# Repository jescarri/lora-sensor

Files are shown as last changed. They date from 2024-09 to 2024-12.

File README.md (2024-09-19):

# lora-sensor

## Getting started

To make it easy for you to get started with GitLab, here's a list of recommended next steps.

Already a pro? Just edit this README.md and make it your own. Want to make it easy? [Use the template at the bottom](#editing-this-readme)!

## Add your files

- [ ] [Create](https://docs.gitlab.com/ee/user/project/repository/web_editor.html#create-a-file) or [upload](https://docs.gitlab.com/ee/user/project/repository/web_editor.html#upload-a-file) files
- [ ] [Add files using the command line](https://docs.gitlab.com/ee/gitlab-basics/add-file.html#add-a-file-using-the-command-line) or push an existing Git repository with the following command:

```
cd existing_repo
git remote add origin https://gitlab.identitylabs.mx/iot/lora-sensor.git
git branch -M master
git push -uf origin master
```

## Integrate with your tools

- [ ] [Set up project integrations](https://gitlab.identitylabs.mx/iot/lora-sensor/-/settings/integrations)

## Collaborate with your team

- [ ] [Invite team members and collaborators](https://docs.gitlab.com/ee/user/project/members/)
- [ ] [Create a new merge request](https://docs.gitlab.com/ee/user/project/merge_requests/creating_merge_requests.html)
- [ ] [Automatically close issues from merge requests](https://docs.gitlab.com/ee/user/project/issues/managing_issues.html#closing-issues-automatically)
- [ ] [Enable merge request approvals](https://docs.gitlab.com/ee/user/project/merge_requests/approvals/)
- [ ] [Set auto-merge](https://docs.gitlab.com/ee/user/project/merge_requests/merge_when_pipeline_succeeds.html)

## Test and Deploy

Use the built-in continuous integration in GitLab.

- [ ] [Get started with GitLab CI/CD](https://docs.gitlab.com/ee/ci/quick_start/index.html)
- [ ] [Analyze your code for known vulnerabilities with Static Application Security Testing (SAST)](https://docs.gitlab.com/ee/user/application_security/sast/)
- [ ] [Deploy to Kubernetes, Amazon EC2, or Amazon ECS using Auto Deploy](https://docs.gitlab.com/ee/topics/autodevops/requirements.html)
- [ ] [Use pull-based deployments for improved Kubernetes management](https://docs.gitlab.com/ee/user/clusters/agent/)
- [ ] [Set up protected environments](https://docs.gitlab.com/ee/ci/environments/protected_environments.html)

***

# Editing this README

When you're ready to make this README your own, just edit this file and use the handy template below (or feel free to structure it however you want - this is just a starting point!). Thanks to [makeareadme.com](https://www.makeareadme.com/) for this template.

## Suggestions for a good README

Every project is different, so consider which of these sections apply to yours. The sections used in the template are suggestions for most open source projects. Also keep in mind that while a README can be too long and detailed, too long is better than too short. If you think your README is too long, consider utilizing another form of documentation rather than cutting out information.

## Name
Choose a self-explaining name for your project.

## Description
Let people know what your project can do specifically. Provide context and add a link to any reference visitors might be unfamiliar with. A list of Features or a Background subsection can also be added here. If there are alternatives to your project, this is a good place to list differentiating factors.

## Badges
On some READMEs, you may see small images that convey metadata, such as whether or not all the tests are passing for the project. You can use Shields to add some to your README. Many services also have instructions for adding a badge.

## Visuals
Depending on what you are making, it can be a good idea to include screenshots or even a video (you'll frequently see GIFs rather than actual videos). Tools like ttygif can help, but check out Asciinema for a more sophisticated method.

## Installation
Within a particular ecosystem, there may be a common way of installing things, such as using Yarn, NuGet, or Homebrew. However, consider the possibility that whoever is reading your README is a novice and would like more guidance. Listing specific steps helps remove ambiguity and gets people to using your project as quickly as possible. If it only runs in a specific context like a particular programming language version or operating system or has dependencies that have to be installed manually, also add a Requirements subsection.

## Usage
Use examples liberally, and show the expected output if you can. It's helpful to have inline the smallest example of usage that you can demonstrate, while providing links to more sophisticated examples if they are too long to reasonably include in the README.

## Support
Tell people where they can go to for help. It can be any combination of an issue tracker, a chat room, an email address, etc.

## Roadmap
If you have ideas for releases in the future, it is a good idea to list them in the README.

## Contributing
State if you are open to contributions and what your requirements are for accepting them.

For people who want to make changes to your project, it's helpful to have some documentation on how to get started. Perhaps there is a script that they should run or some environment variables that they need to set. Make these steps explicit. These instructions could also be useful to your future self.

You can also document commands to lint the code or run tests. These steps help to ensure high code quality and reduce the likelihood that the changes inadvertently break something. Having instructions for running tests is especially helpful if it requires external setup, such as starting a Selenium server for testing in a browser.

## Authors and acknowledgment
Show your appreciation to those who have contributed to the project.

## License
For open source projects, say how it is licensed.

## Project status
If you have run out of energy or time for your project, put a note at the top of the README saying that development has slowed down or stopped completely. Someone may choose to fork your project or volunteer to step in as a maintainer or owner, allowing your project to keep going. You can also make an explicit request for maintainers.

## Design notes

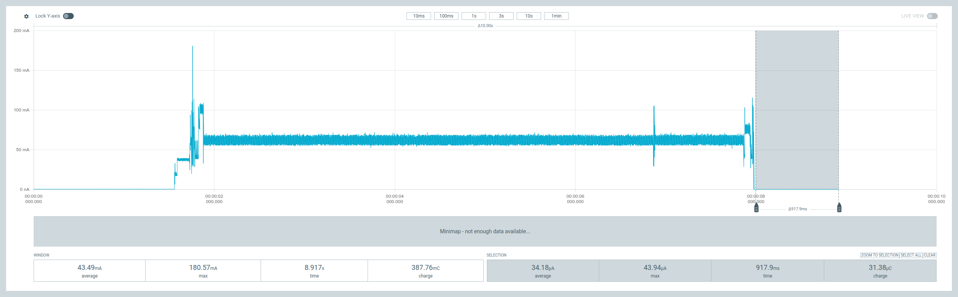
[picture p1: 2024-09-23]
power-profile/radio_vdd_enable_sleep_zoom1.png

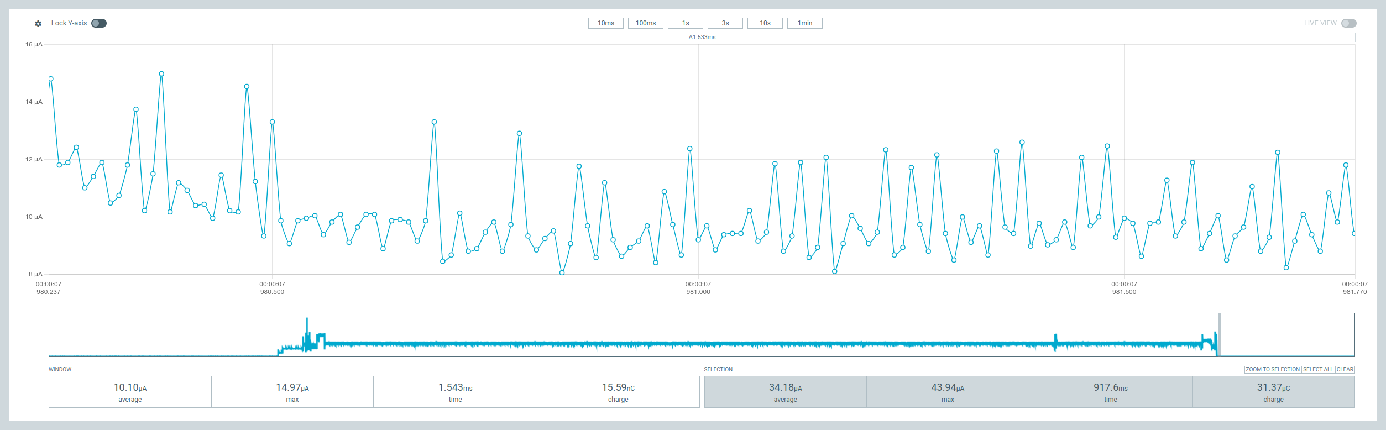
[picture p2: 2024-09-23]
power-profile/radio_vdd_enable_sleep_zoom2.png

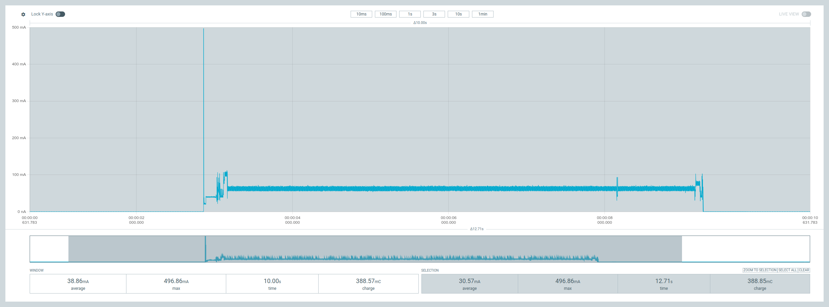
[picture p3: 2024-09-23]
power-profile/no_radio_vdd.png

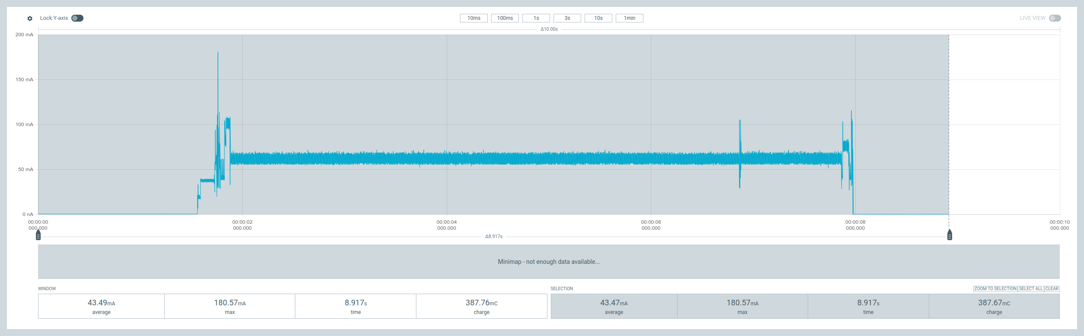
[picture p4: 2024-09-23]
power-profile/radio_vdd_enable.png

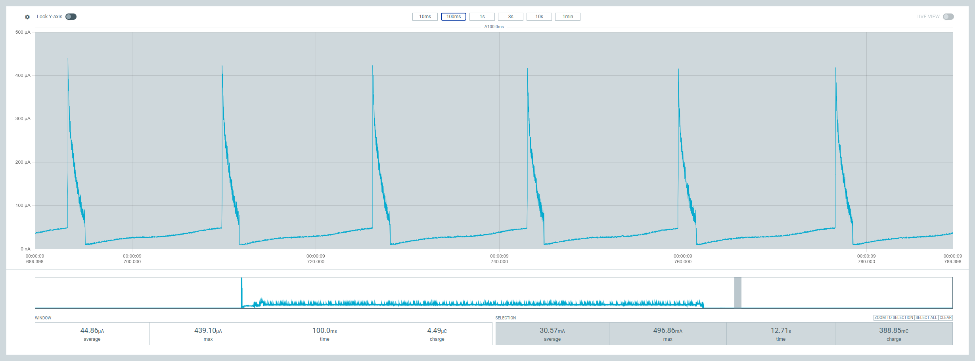
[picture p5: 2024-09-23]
power-profile/no_radio_vdd_sleep_zoom.png

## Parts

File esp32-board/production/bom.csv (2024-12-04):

Designator | Footprint | Quantity | Value | LCSC Part #
+ BAT - | JST_XH_B2B-XH-AM_1x02_P2.50mm_Vertical | 1 | Battery
ANT | U.FL_Molex_MCRF_73412-0110_Vertical | 1 | ANT
C1, C9 | 1206 | 2 | 1uF
C10, C11, C2 | 1206 | 3 | 100nF
C3 | CP_EIA-3528-21_Kemet-B_Pad1.50x2.35mm_HandSolder | 1 | 22uF
C4, C5, C6, C7, C8 | 1206 | 5 | 10uF
CONFIG RESET | SW_PUSH_6mm_H5mm | 1 | WEB_CONF
EXTERNAL CONTROL | JST_XH_B8B-XH-AM_1x08_P2.50mm_Vertical | 1 | remote_header
J5, J6 | PinHeader_1x10_P2.54mm_Vertical | 2 | Conn_01x10_Pin
PROG | SW_PUSH_6mm_H5mm | 1 | ESP Program
R1, R2, R3 | 1206 | 3 | 10K
R4 | 1206 | 1 | 100k
R5, R6 | 1206 | 2 | 2.2K
RESET | SW_PUSH_6mm_H5mm | 1 | RESET
SOIL SENSOR | JST_XH_B3B-XH-AM_1x03_P2.50mm_Vertical | 1 | SOIL_SENSOR
U1 | ESP32-WROOM-32 | 1 | ESP32-WROOM-32D
U2, U3 | SOT-23-5 | 2 | XC6220B331MR
U4 | SOT-23 | 1 | TPS3839DBZ
U5 | HOPERF_RFM9XW_SMD | 1 | RFM95W-915S2
U6 | SON50P200X200X80-9N | 1 | MAX17048G_T10

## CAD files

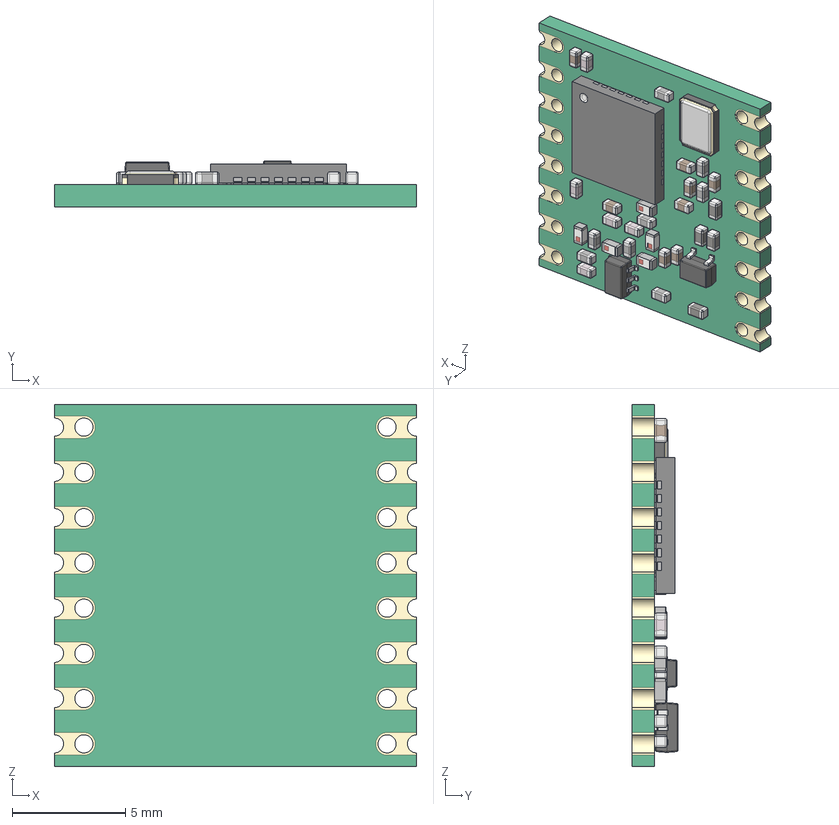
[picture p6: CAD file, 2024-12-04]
esp32-board/models/RFM95/RFM95 LoRa v15.step
16.0 x 2.04 x 16.0 mm
QFN 28
SMD Crystal
CAP 0403 x 8
CAP Ceramic 0403 x 8
Res 0403 x 4
CAP ML 0403 x 5
SOT-323
Inductor SMD 0403 x 5
SOT-363

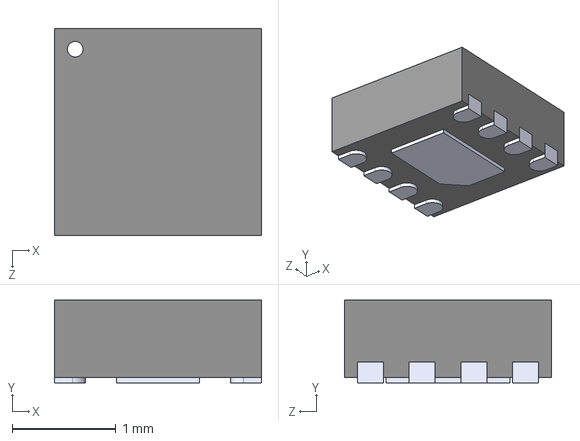
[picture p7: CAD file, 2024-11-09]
esp32-board/models/MAX17048G+T10/MAX17048G_T10.step
2.00 x 0.8 x 2.00 mm

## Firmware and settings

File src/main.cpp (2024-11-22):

#include "WiFi.h"
#include "driver/adc.h"

#include <Preferences.h>
#include <lmic.h>

#include "lorawan.hpp"
#include "lorawan_settings.hpp"
#include "menu.hpp"
#include <Adafruit_MAX1704X.h>
#include <FastLED.h>
#include <Wire.h>
#include <hal/hal.h>

#define VCC_ENA_PIN 13
#define START_WEB_CONFIG_PIN 16
#define NUM_LEDS 1
#define LED_DATA_PIN 17

lmic_t SETTINGS_LMIC;
Preferences lorawan_preferences;
CayenneLPP lpp(MAX_PAYLOAD_SIZE);
Adafruit_MAX17048 maxlipo;
CRGB leds[NUM_LEDS];
bool maxLipoFound = false;

// Active in LOW, normal operation is HIGH
bool startWebConfig = false;

void PrintRuntime();
void GoDeepSleep();
void ReadSensors();

volatile bool enableSleep_ = true;
unsigned long entry;

osjob_t sendjob;

const lmic_pinmap lmic_pins = {
    .nss = PIN_LMIC_NSS,
    .rxtx = LMIC_UNUSED_PIN,
    .rst = PIN_LMIC_RST,
    .dio = {PIN_LMIC_DIO0, PIN_LMIC_DIO1, PIN_LMIC_DIO2},
    .rxtx_rx_active = 0,
    .spi_freq = 8000000,
};

// Schedule TX every this many seconds
// Respect Fair Access Policy and Maximum Duty Cycle!
// https://www.thethingsnetwork.org/docs/lorawan/duty-cycle.html
// https://www.loratools.nl/#/airtime
const unsigned TX_INTERVAL = 3600;

void setup() {
  pinMode(VCC_ENA_PIN, OUTPUT);
  digitalWrite(VCC_ENA_PIN, HIGH);
  pinMode(START_WEB_CONFIG_PIN, INPUT);
  WiFi.mode(WIFI_OFF);
  btStop();

  Wire.begin(21, 22);
  delay(100);
  Serial.begin(115200);
  adc_power_acquire();
  randomSeed(analogRead(0));
  // Init and Wake the Lipo Cel:
  if (maxlipo.begin()) {
    // Wake up the lipo gauge
    maxlipo.wake();
    maxLipoFound = true;
  } else {
    Serial.println("No MAX14048 found");
  }
  FastLED.addLeds<WS2812B, LED_DATA_PIN, GRB>(leds, NUM_LEDS);
  FastLED.setBrightness(50);
  lorawan_preferences_init();
  Serial.print("LMIC CONFIG Present: ");
  Serial.println(lorawanConfigPresent());
  startWebConfig = !digitalRead(START_WEB_CONFIG_PIN);
  Serial.print("Webconf status: ");
  Serial.println(startWebConfig);
  bool otaa_cfg = lorawan_preferences.isKey("ttn_otaa_config");
  Serial.print("otaa_config_done: ");
  Serial.println(otaa_cfg);
  Serial.print("Sleeping for: ");
  Serial.print(get_sleep_time_seconds());
  Serial.println(" seconds");

  if ((startWebConfig == true) || (!otaa_cfg)) {
    resetLmic();
    startWebConf();
  }

  PrintLMICVersion();
  // LMIC init
  os_init();

  LMIC_reset();
  if (!lmic_init_needed()) {
    Serial.println(LMIC.seqnoUp);
    Serial.println("LMIC Data found");
    load_lmic();

    Serial.println(LMIC.seqnoUp);
  }

  LoraWANDebug(LMIC);

  // Start job (sending automatically starts OTAA too)
  LMIC_selectSubBand(1);

  do_send(&sendjob);
  entry = millis();
}

void loop() {
  static unsigned long lastPrintTime = 0;
  os_runloop_once();
  const bool timeCriticalJobs =
      os_queryTimeCriticalJobs(ms2osticksRound((TX_INTERVAL * 1000)));

  if (!timeCriticalJobs && enableSleep_ == true &&
      !(LMIC.opmode & OP_TXRXPEND)) {
    Serial.print(F("Can go sleep "));
    LoraWANPrintLMICOpmode();
    lmic_save();
    GoDeepSleep();
  } else if (lastPrintTime + 1000 < millis()) {
    Serial.print(F("Cannot sleep "));
    Serial.print(F("TimeCriticalJobs: "));
    Serial.print(timeCriticalJobs);
    Serial.print(" ");

    LoraWANPrintLMICOpmode();
    PrintRuntime();
    lastPrintTime = millis();
  }
  if (millis() - entry > 60000) {
    // ToDo: Delete LMIC config from nvram
    // so it joins the wan after next run
    resetLmic();
    GoDeepSleep();
  }
}

void PrintRuntime() {
  long seconds = millis() / 1000;
  Serial.print("Runtime: ");
  Serial.print(seconds);
  Serial.println(" seconds");
}

void GoDeepSleep() {
  // Turn off the lipo gauge:
  //
  int sleepTime = get_sleep_time_seconds();
  Serial.println("Going to DeepSleep for: ");
  Serial.println(sleepTime);
  leds[0] = CRGB::Black;
  FastLED.show();
  maxlipo.hibernate();
  digitalWrite(VCC_ENA_PIN, LOW);
  WiFi.mode(WIFI_OFF);
  btStop();
  gpio_reset_pin(GPIO_NUM_0);
  gpio_reset_pin(GPIO_NUM_2);
  gpio_reset_pin(GPIO_NUM_4);
  gpio_reset_pin(GPIO_NUM_12);
  gpio_reset_pin(GPIO_NUM_13);
  gpio_reset_pin(GPIO_NUM_14);
  gpio_reset_pin(GPIO_NUM_15);
  gpio_reset_pin(GPIO_NUM_25);
  gpio_reset_pin(GPIO_NUM_26);
  gpio_reset_pin(GPIO_NUM_27);
  gpio_reset_pin(GPIO_NUM_32);
  gpio_reset_pin(GPIO_NUM_33);
  gpio_reset_pin(GPIO_NUM_34);
  gpio_reset_pin(GPIO_NUM_35);
  gpio_reset_pin(GPIO_NUM_36);
  gpio_reset_pin(GPIO_NUM_37);
  gpio_reset_pin(GPIO_NUM_38);
  gpio_reset_pin(GPIO_NUM_39);
  adc_power_release();
  Serial.println(F("Go DeepSleep"));
  PrintRuntime();
  Serial.flush();
  esp_sleep_enable_timer_wakeup(sleepTime * 1000000ull);
  esp_deep_sleep_start();
}

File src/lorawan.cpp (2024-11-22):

#include "lorawan.hpp"
#include "lorawan_settings.hpp"
#include <Adafruit_MAX1704X.h>

sensorData sd;

void LoraWANPrintLMICOpmode(void) {
  Serial.print(F("LMIC.opmode: "));
  if (LMIC.opmode & OP_NONE) {
    Serial.print(F("OP_NONE "));
  }
  if (LMIC.opmode & OP_SCAN) {
    Serial.print(F("OP_SCAN "));
  }
  if (LMIC.opmode & OP_TRACK) {
    Serial.print(F("OP_TRACK "));
  }
  if (LMIC.opmode & OP_JOINING) {
    Serial.print(F("OP_JOINING "));
  }
  if (LMIC.opmode & OP_TXDATA) {
    Serial.print(F("OP_TXDATA "));
  }
  if (LMIC.opmode & OP_POLL) {
    Serial.print(F("OP_POLL "));
  }
  if (LMIC.opmode & OP_REJOIN) {
    Serial.print(F("OP_REJOIN "));
  }
  if (LMIC.opmode & OP_SHUTDOWN) {
    Serial.print(F("OP_SHUTDOWN "));
  }
  if (LMIC.opmode & OP_TXRXPEND) {
    Serial.print(F("OP_TXRXPEND "));
  }
  if (LMIC.opmode & OP_RNDTX) {
    Serial.print(F("OP_RNDTX "));
  }
  if (LMIC.opmode & OP_PINGINI) {
    Serial.print(F("OP_PINGINI "));
  }
  if (LMIC.opmode & OP_PINGABLE) {
    Serial.print(F("OP_PINGABLE "));
  }
  if (LMIC.opmode & OP_NEXTCHNL) {
    Serial.print(F("OP_NEXTCHNL "));
  }
  if (LMIC.opmode & OP_LINKDEAD) {
    Serial.print(F("OP_LINKDEAD "));
  }
  if (LMIC.opmode & OP_LINKDEAD) {
    Serial.print(F("OP_LINKDEAD "));
  }
  if (LMIC.opmode & OP_TESTMODE) {
    Serial.print(F("OP_TESTMODE "));
  }
  if (LMIC.opmode & OP_UNJOIN) {
    Serial.print(F("OP_UNJOIN "));
  }
}

void LoraWANDebug(lmic_t lmic_check) {

  LoraWANPrintLMICOpmode();
  Serial.println("");
  Serial.println("-----");

  Serial.print(F("LMIC.seqnoUp = "));
  Serial.println(lmic_check.seqnoUp);

  Serial.print(F("LMIC.globalDutyRate = "));
  Serial.print(lmic_check.globalDutyRate);
  Serial.print(F(" osTicks, "));
  Serial.print(osticks2ms(lmic_check.globalDutyRate) / 1000);
  Serial.println(F(" sec"));

  Serial.print(F("LMIC.globalDutyAvail = "));
  Serial.print(lmic_check.globalDutyAvail);
  Serial.print(F(" osTicks, "));
  Serial.print(osticks2ms(lmic_check.globalDutyAvail) / 1000);
  Serial.println(F(" sec"));

  Serial.print(F("LMICbandplan_nextTx = "));
  Serial.print(LMICbandplan_nextTx(os_getTime()));
  Serial.print(F(" osTicks, "));
  Serial.print(osticks2ms(LMICbandplan_nextTx(os_getTime())) / 1000);
  Serial.println(F(" sec"));

  Serial.print(F("os_getTime = "));
  Serial.print(os_getTime());
  Serial.print(F(" osTicks, "));
  Serial.print(osticks2ms(os_getTime()) / 1000);
  Serial.println(F(" sec"));

  Serial.print(F("LMIC.txend = "));
  Serial.println(lmic_check.txend);
  Serial.print(F("LMIC.txChnl = "));
  Serial.println(lmic_check.txChnl);

  Serial.println("");
  Serial.println("");
}

void PrintLMICVersion() {
  Serial.print(F("LMIC: "));
  Serial.print(ARDUINO_LMIC_VERSION_GET_MAJOR(ARDUINO_LMIC_VERSION));
  Serial.print(F("."));
  Serial.print(ARDUINO_LMIC_VERSION_GET_MINOR(ARDUINO_LMIC_VERSION));
  Serial.print(F("."));
  Serial.print(ARDUINO_LMIC_VERSION_GET_PATCH(ARDUINO_LMIC_VERSION));
  Serial.print(F("."));
  Serial.println(ARDUINO_LMIC_VERSION_GET_LOCAL(ARDUINO_LMIC_VERSION));
}

void onEvent(ev_t ev) {
  Serial.print(os_getTime());
  Serial.print(": ");
  switch (ev) {
  case EV_SCAN_TIMEOUT:
    Serial.println(F("EV_SCAN_TIMEOUT"));
    break;
  case EV_BEACON_FOUND:
    Serial.println(F("EV_BEACON_FOUND"));
    break;
  case EV_BEACON_MISSED:
    Serial.println(F("EV_BEACON_MISSED"));
    break;
  case EV_BEACON_TRACKED:
    Serial.println(F("EV_BEACON_TRACKED"));
    break;
  case EV_JOINING:
    Serial.println(F("EV_JOINING"));
    leds[0] = CRGB::DarkOrange;
    FastLED.show();
    break;
  case EV_JOINED:
    Serial.println(F("EV_JOINED"));
    {
      u4_t netid = 0;
      devaddr_t devaddr = 0;
      u1_t nwkKey[16];
      u1_t artKey[16];
      LMIC_getSessionKeys(&netid, &devaddr, nwkKey, artKey);
      Serial.print("netid: ");
      Serial.println(netid, DEC);
      Serial.print("devaddr: ");
      Serial.println(devaddr, HEX);
      Serial.print("artKey: ");
      for (size_t i = 0; i < sizeof(artKey); ++i) {
        Serial.print(artKey[i], HEX);
      }
      Serial.println("");
      Serial.print("nwkKey: ");
      for (size_t i = 0; i < sizeof(nwkKey); ++i) {
        Serial.print(nwkKey[i], HEX);
      }
      Serial.println("");
    }
    // Disable link check validation (automatically enabled
    // during join, but because slow data rates change max TX
    // size, we don't use it in this example.
    LMIC_setLinkCheckMode(0);
    leds[0] = CRGB::Green;
    FastLED.show();
    delay(1000);
    break;
  case EV_JOIN_FAILED:
    Serial.println(F("EV_JOIN_FAILED"));
    break;
  case EV_REJOIN_FAILED:
    Serial.println(F("EV_REJOIN_FAILED"));
    break;
  case EV_TXCOMPLETE:
    // Transmit completed, includes waiting for RX windows.
    Serial.println(F("EV_TXCOMPLETE (includes waiting for RX windows)"));
    // setTxIndicatorsOn(false);
    // printEvent(timestamp, ev);
    // printFrameCounters();
    // Check if downlink was received
    if (LMIC.dataLen != 0 || LMIC.dataBeg != 0) {
      uint8_t fPort = 0;
      if (LMIC.txrxFlags & TXRX_PORT) {
        fPort = LMIC.frame[LMIC.dataBeg - 1];
      }
      // printDownlinkInfo();
      // processDownlink(timestamp, fPort, LMIC.frame + LMIC.dataBeg,
      // LMIC.dataLen);
    }
    enableSleep_ = true;
    break;
  case EV_LOST_TSYNC:
    Serial.println(F("EV_LOST_TSYNC"));
    break;
  case EV_RESET:
    Serial.println(F("EV_RESET"));
    break;
  case EV_RXCOMPLETE:
    // data received in ping slot
    Serial.println(F("EV_RXCOMPLETE"));
    break;
  case EV_LINK_DEAD:
    Serial.println(F("EV_LINK_DEAD"));
    break;
  case EV_LINK_ALIVE:
    Serial.println(F("EV_LINK_ALIVE"));
    break;
  /*
      || This event is defined but not used in the code. No
      || point in wasting codespace on it.
      ||
      || case EV_SCAN_FOUND:
      ||    Serial.println(F("EV_SCAN_FOUND"));
      ||    break;
  */
  case EV_TXSTART:
    Serial.println(F("EV_TXSTART"));
    break;
  case EV_TXCANCELED:
    Serial.println(F("EV_TXCANCELED"));
    break;
  case EV_RXSTART:
    /* do not print anything -- it wrecks timing */
    break;
  case EV_JOIN_TXCOMPLETE:
    Serial.println(F("EV_JOIN_TXCOMPLETE: no JoinAccept"));
    break;
  default:
    Serial.print(F("Unknown event: "));
    Serial.println((unsigned)ev);
    break;
  }
}
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

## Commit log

2024-09-23 Working Software and hardware
    Initial current measurements.
2024-09-25 ADD: sensor read + CayenneLPP support
2024-09-26 FIX: use unsigned cayenneLPP datatype for ADC reads.
    [lorawan.cpp, lorawan_settings.cpp, main.cpp]
2024-09-28 ADD: Support for config menu via wireless
2024-09-29 ENABLE: radio pin
2024-09-30 Completed support for privisioning the device via wifi.
2024-11-09 ADD: Kicad project and sensor read rework
    [MAX17048G_T10.step, esp32-board.kicad_pcb, esp32-board.kicad_sch]
2024-11-09 ADD: support for lipo gauge
2024-11-12 ADDED: Support for led status
2024-11-12 ADD: LED Pin in Schematic
    [esp32-board.kicad_sch]
2024-11-22 ADD: Calibration and sleep time web menu config
2024-11-23 COMPLETED: Schematic, footprint assignment
    WIP PCB
    [esp32-board.kicad_pcb, esp32-board.kicad_sch]
2024-12-04 ADD: Final PCB
    [RFM95 LoRa v15.step, bom.csv, designators.csv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]
2024-12-11 fixes to schematic and PCB
    This change contains the following fixes on schematic:
    - U3 VIN is now connected to V_BAT
    - C7 and C5 are now 4.7 uF as specified in data sheet
    Changes to PCB:
    - Fixed U3 VIN routing
    - Simplified routing for PROGRAM and START_WEB_CONFIG switches
    - VBAT traces are now 15 mil
    - Rerouted traces as to avoid being direclty below ESP and lora modules
    - Added dedicated labels to the above switches
    - Moved C6 and C7 closer to U3
    - Simplified routing of several traces
    - Fixed issues with silkscreen
    [esp32-board.kicad_pcb, esp32-board.kicad_sch]
2024-12-11 Revert "fixes to schematic and PCB"
    This reverts commit 3e7eab6521abb5c68805baea498affc1a11a7eaf.
    [esp32-board.kicad_pcb, esp32-board.kicad_sch]
